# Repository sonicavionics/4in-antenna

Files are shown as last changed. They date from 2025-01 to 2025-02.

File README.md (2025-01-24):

# Antenna Module Repository

Use Export KiCad Images Workflow

---

<div align="center">
  <div>
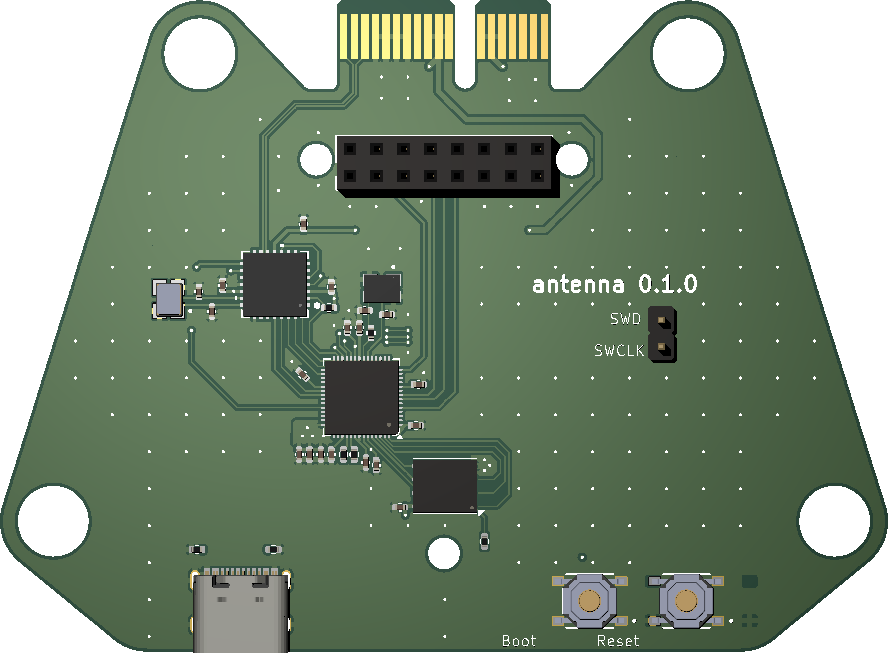
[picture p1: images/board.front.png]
    
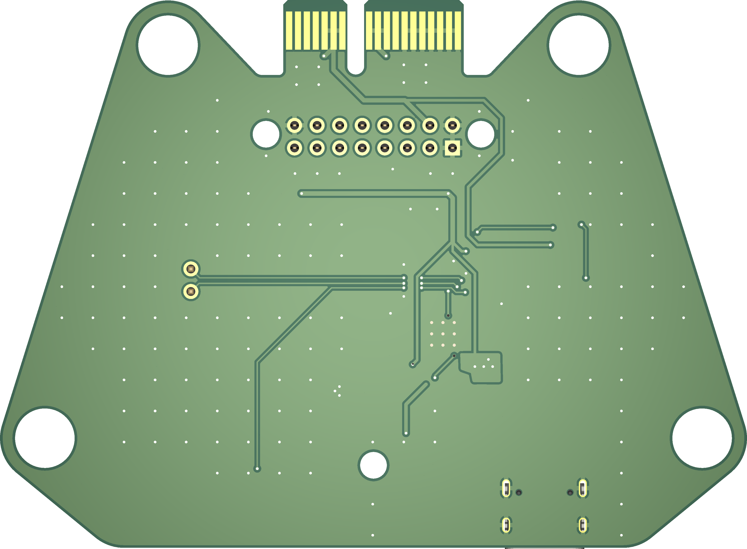
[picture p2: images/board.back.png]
    
    <p><em>3D Render</em></p>
  </div>
  <br>

  <div>
    Schematic<br>
    <p><em>Schematic</em></p>
  </div>
  <br>
  
  <div>
    Front
    Back<br>
    <em>Footprint</em>
  </div>
</div>

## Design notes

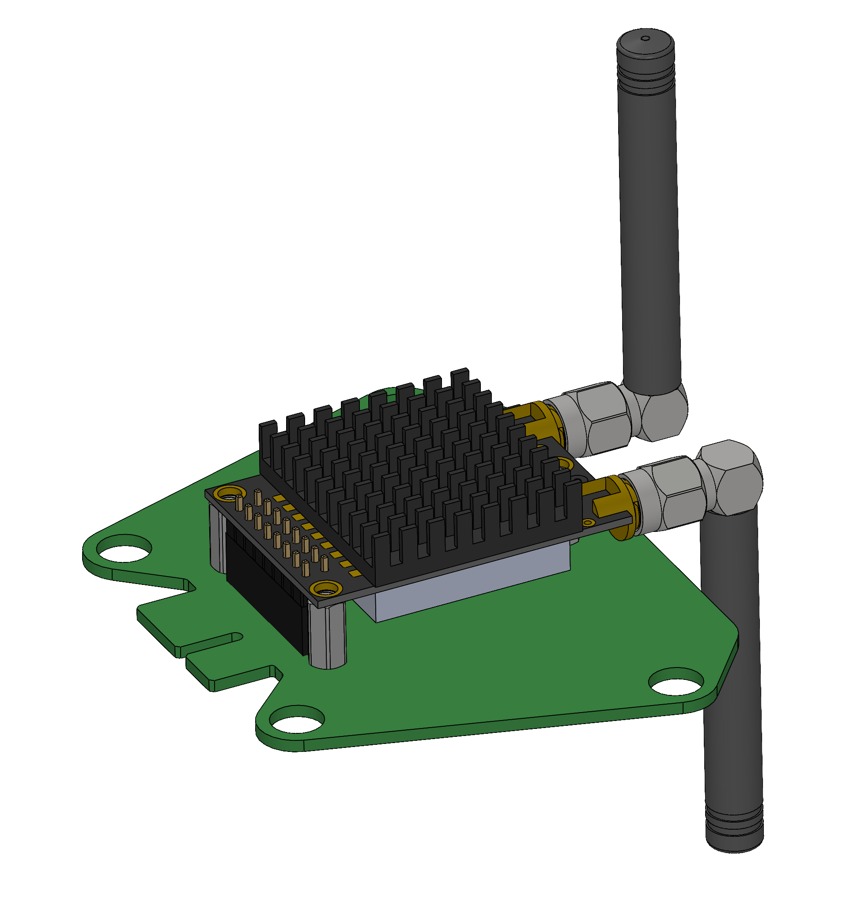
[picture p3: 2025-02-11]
mcad_exports/images/rfd_board.PNG

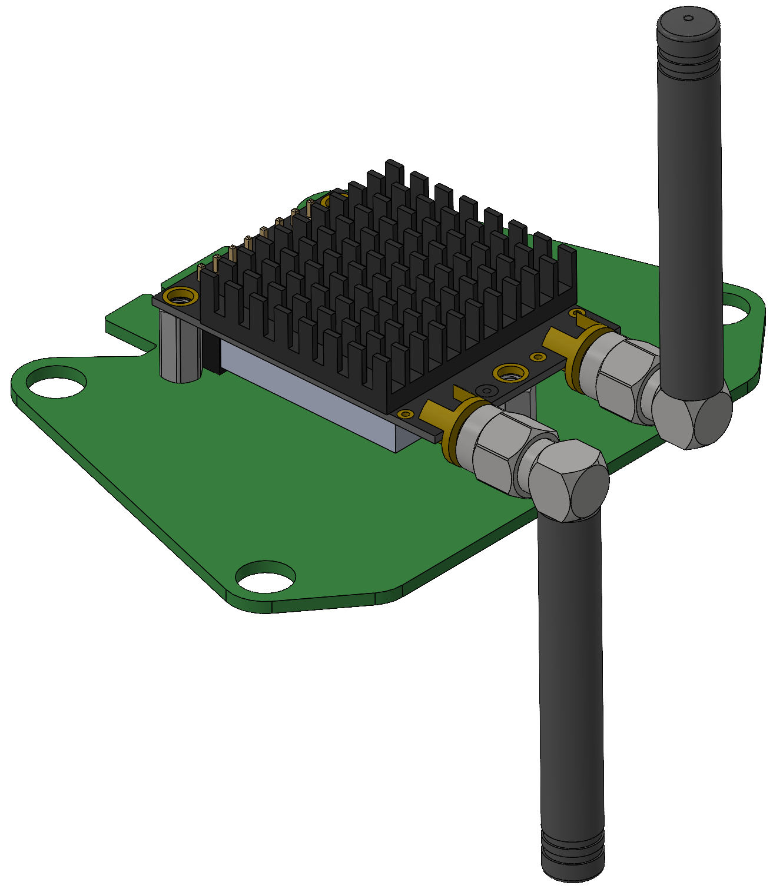
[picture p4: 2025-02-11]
mcad_exports/images/rfd_board2.PNG

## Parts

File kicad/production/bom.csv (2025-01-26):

Designator | Footprint | Quantity | Value | LCSC Part #
C10, C11 | 0402 | 2 | 15p | C1548
C206, C207, C209, C211, C212, C213, C214, C215, C216, C40, C90, C92, C93 | 0402 | 13 | 100n | C307331
C208, C210 | 0402 | 2 | 1u | C52923
C94, C95 | 0402 | 2 | 22p | C1555
J5 | PinSocket_2x08_P2.54mm_Vertical | 1 | Conn_02x08_Odd_Even
J6 | USB_C_Receptacle_Palconn_UTC16-G | 1 | USB_C_Receptacle_USB2.0_16P | C2765186
R12, R30 | 0402 | 2 | 1k | C11702
R203, R204 | 0402 | 2 | 27 | C25100
R3, R4 | 0402 | 2 | 5.1k | C25905
R91 | 0402 | 1 | 10k | C25744
S1, S2 | SW_TS-1187A-B-A-B | 2 | TS-1187A-B-A-B | C318884
U2 | QFN-56-1EP_7x7mm_P0.4mm_EP3.2x3.2mm | 1 | RP2040 | C2040
U4 | WSON-8-1EP_6x5mm_P1.27mm_EP3.4x4.3mm | 1 | W25Q128JVP | C190862
U9 | QFN28_6X6MC_MCH | 1 | MCP25625T-E/ML | C191253
X1 | ABM8-272-T3_ABR | 1 | ABM8-272-T3 | C20625731
Y2 | OSC_X322516MLB4SI | 1 | X322516MLB4SI | C12668

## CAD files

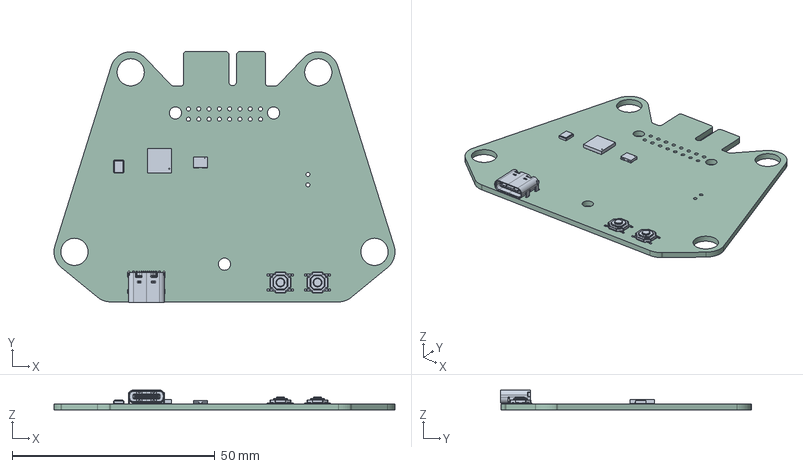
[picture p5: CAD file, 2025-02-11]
images/board.step
84.1 x 61.9 x 4.91 mm
X322516MLB4SI
TS-1187A-B-A-B x 2
QFN28_6X6MC_MCH
USB_C_Receptacle_GCT_USB4105-xx-A_16P_TopMnt_Horizontal
ABM8-272-T3_ABR
antenna_PCB

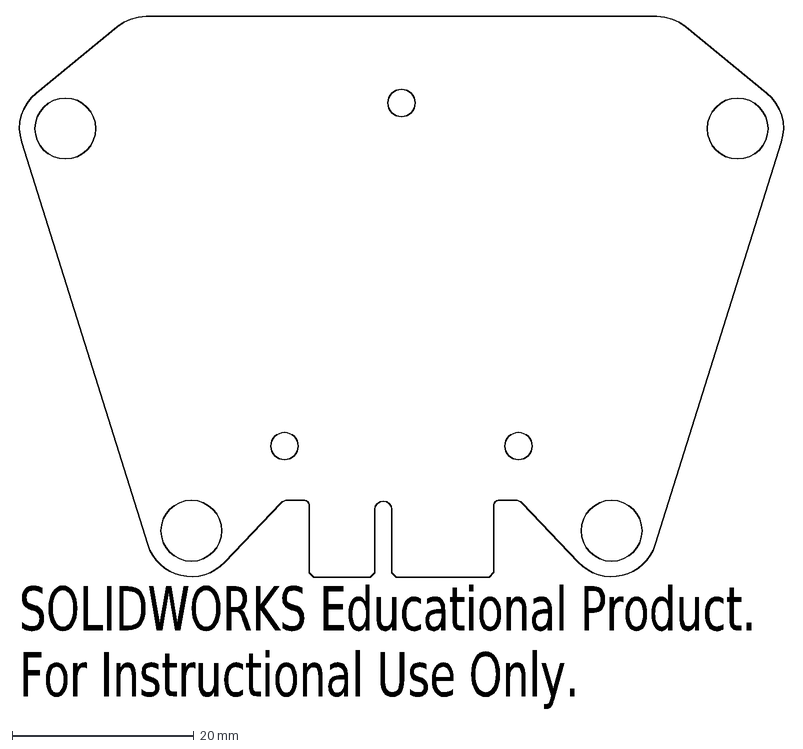
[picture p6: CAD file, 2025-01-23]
mcad_exports/dxf/rfd_card.DXF
SOLIDWORKS Educational Product.
For Instructional Use Only.

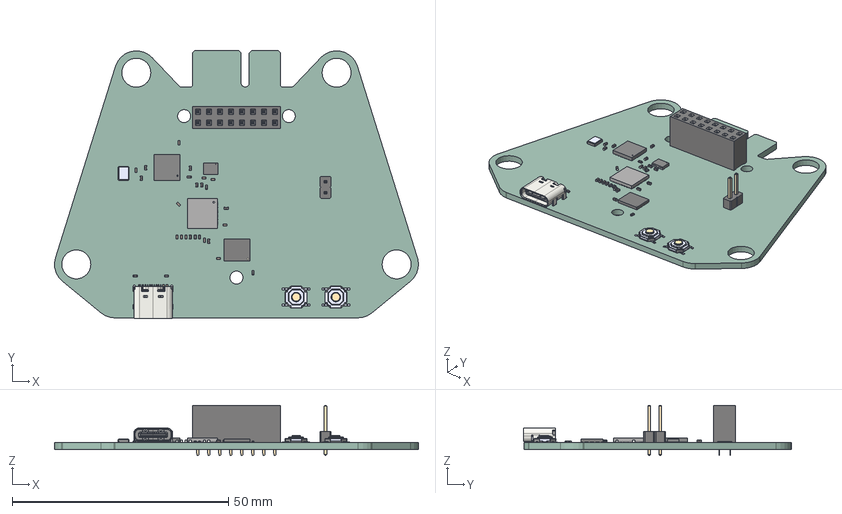
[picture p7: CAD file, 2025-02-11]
solidworks/kicad_pcb.step
84.1 x 61.9 x 11.6 mm
WSON-8-1EP_6x5mm_P1.27mm_EP3.4x4.3mm
C_0402_1005Metric x 19
R_0402_1005Metric x 7
X322516MLB4SI
TS-1187A-B-A-B x 2
USB_C_Receptacle_16P_TopMnt_Horizontal_GCT_USB4105-xx-A
PinSocket_2x08_P2.54mm_Vertical
QFN_56_1EP_7x7mm_P04mm_EP32x32mm
PinHeader_1x02_P254mm_Vertical
antenna_PCB

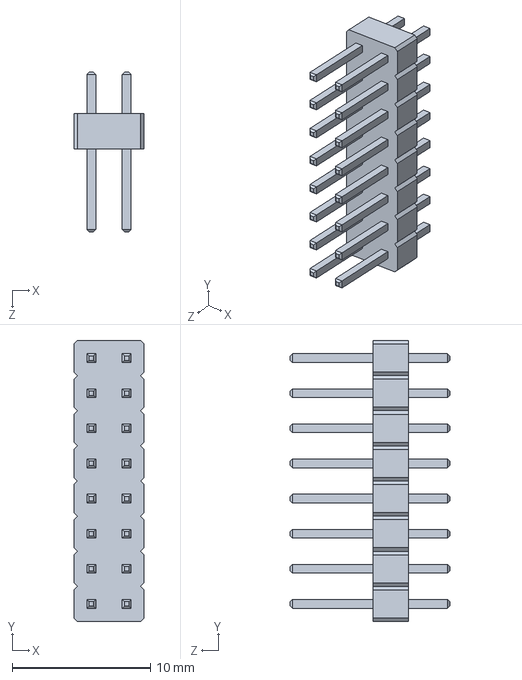
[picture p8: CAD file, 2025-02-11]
solidworks/PinHeader_2x08_P2.54mm_Vertical.SLDPRT
5.08 x 20.3 x 11.5 mm

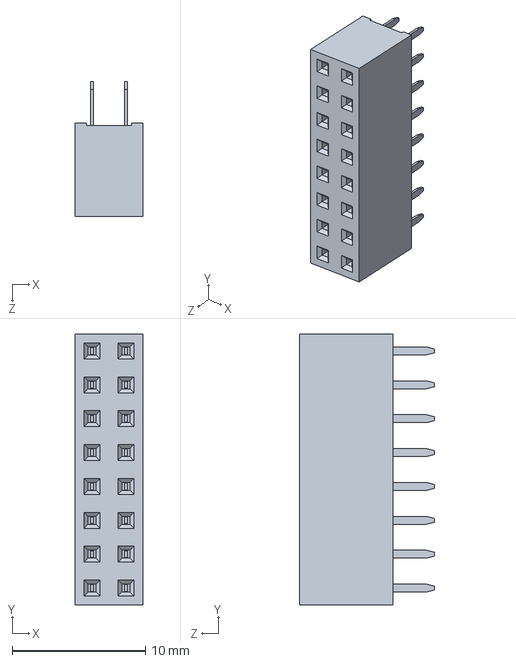
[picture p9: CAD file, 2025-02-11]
solidworks/PinSocket_2x08_P2.54mm_Vertical.SLDPRT
5.08 x 20.3 x 10.1 mm

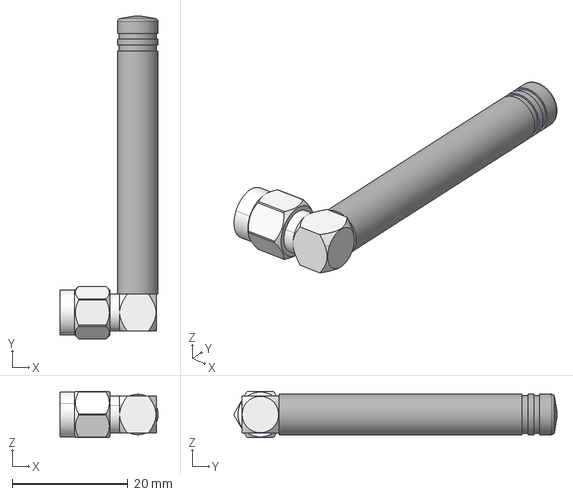
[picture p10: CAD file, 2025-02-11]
solidworks/GSM_ANTENNA_45mm_90deg.step
16.9 x 55.7 x 8.00 mm
RP-SMA FEMALE TO 90DEG MALE

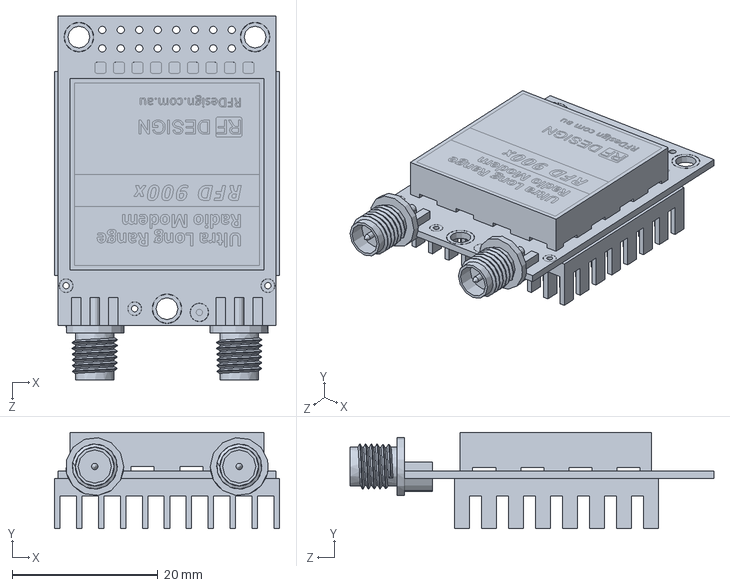
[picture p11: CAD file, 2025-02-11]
solidworks/RFD 900+.SLDPRT
30.9 x 13.2 x 50.0 mm

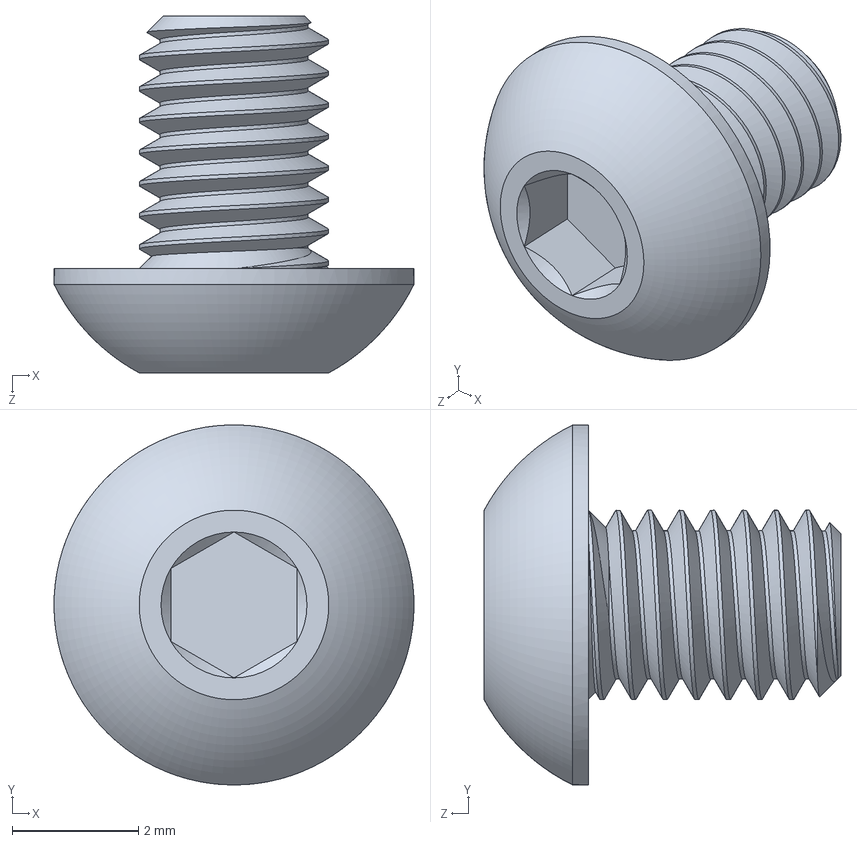
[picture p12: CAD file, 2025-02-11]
solidworks/92095A471_Button Head Hex Drive Screw.SLDPRT
5.70 x 5.70 x 5.65 mm

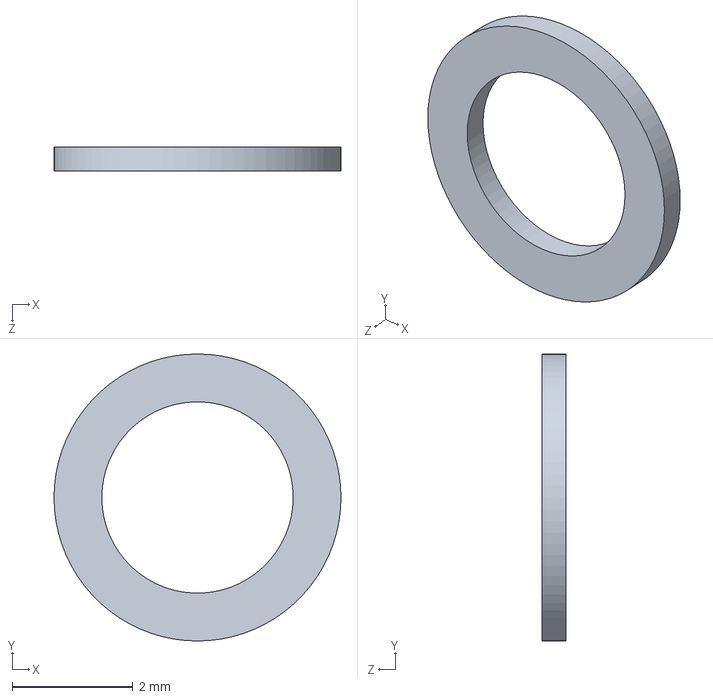
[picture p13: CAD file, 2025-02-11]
solidworks/97022A879_316 Stainless Steel Ring Shim.SLDPRT
4.76 x 4.76 x 0.406 mm

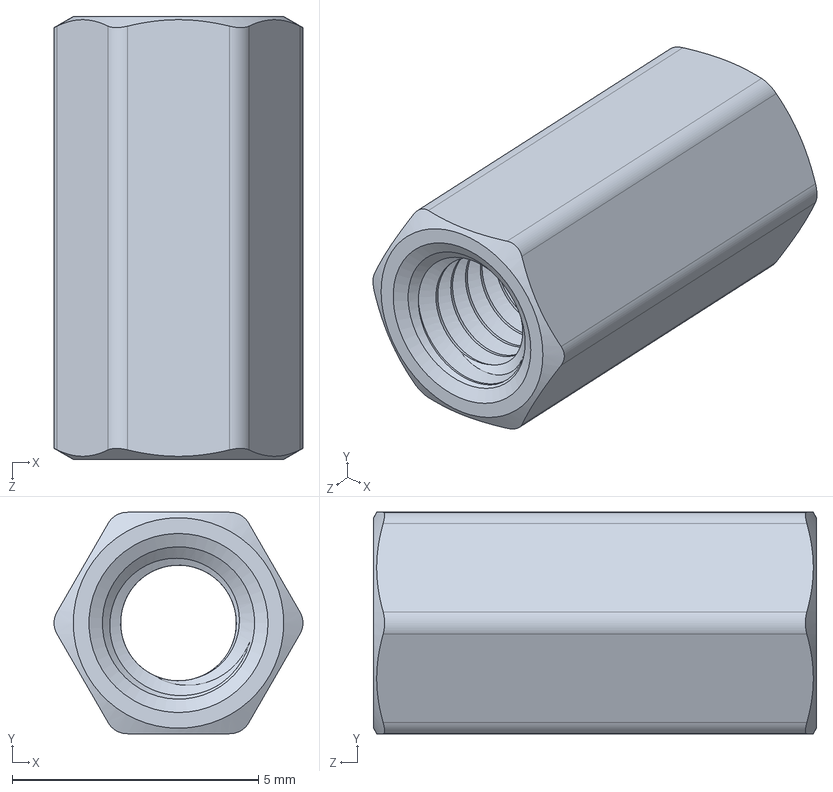
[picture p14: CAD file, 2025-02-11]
solidworks/94868A719_Female Threaded Hex Standoff(1).SLDPRT
5.06 x 4.50 x 9.00 mm

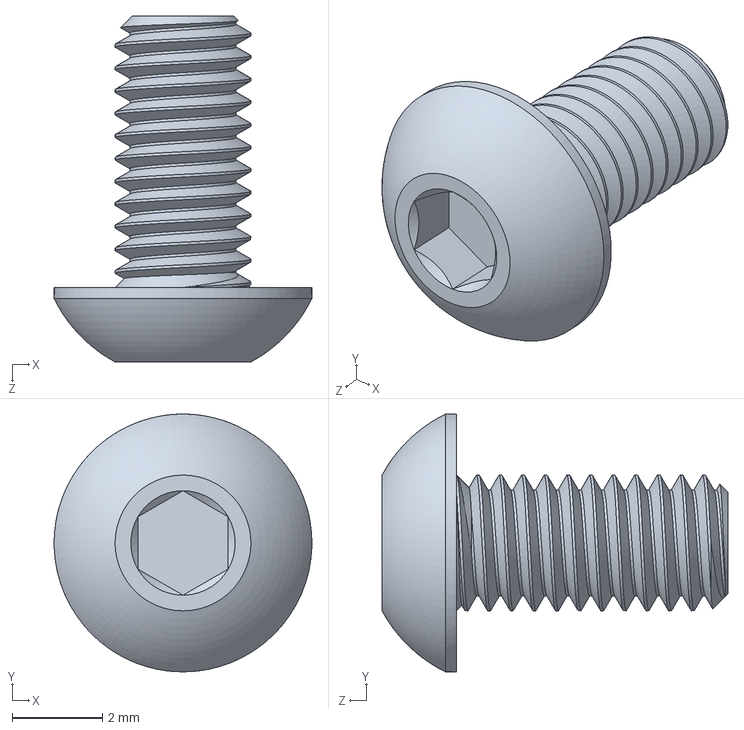
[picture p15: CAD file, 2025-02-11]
solidworks/92095A179_Button Head Hex Drive Screw.SLDPRT
5.70 x 5.70 x 7.65 mm

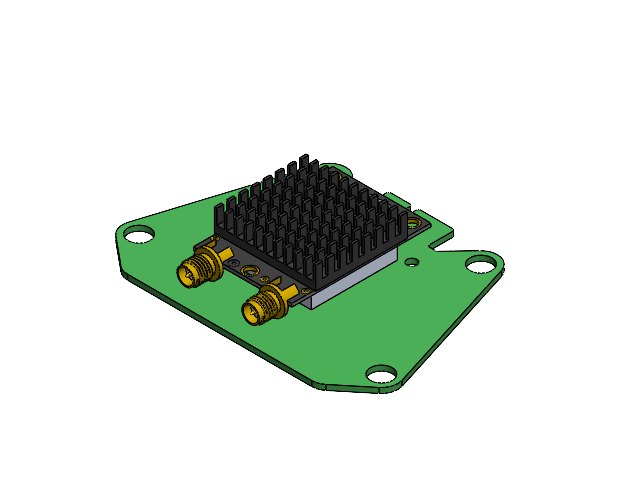
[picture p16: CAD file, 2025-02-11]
solidworks/rfd_board1.SLDASM
RFD 900+
board

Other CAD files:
solidworks/RP-SMA FEMALE TO 90DEG MALE_1.step.SLDPRT

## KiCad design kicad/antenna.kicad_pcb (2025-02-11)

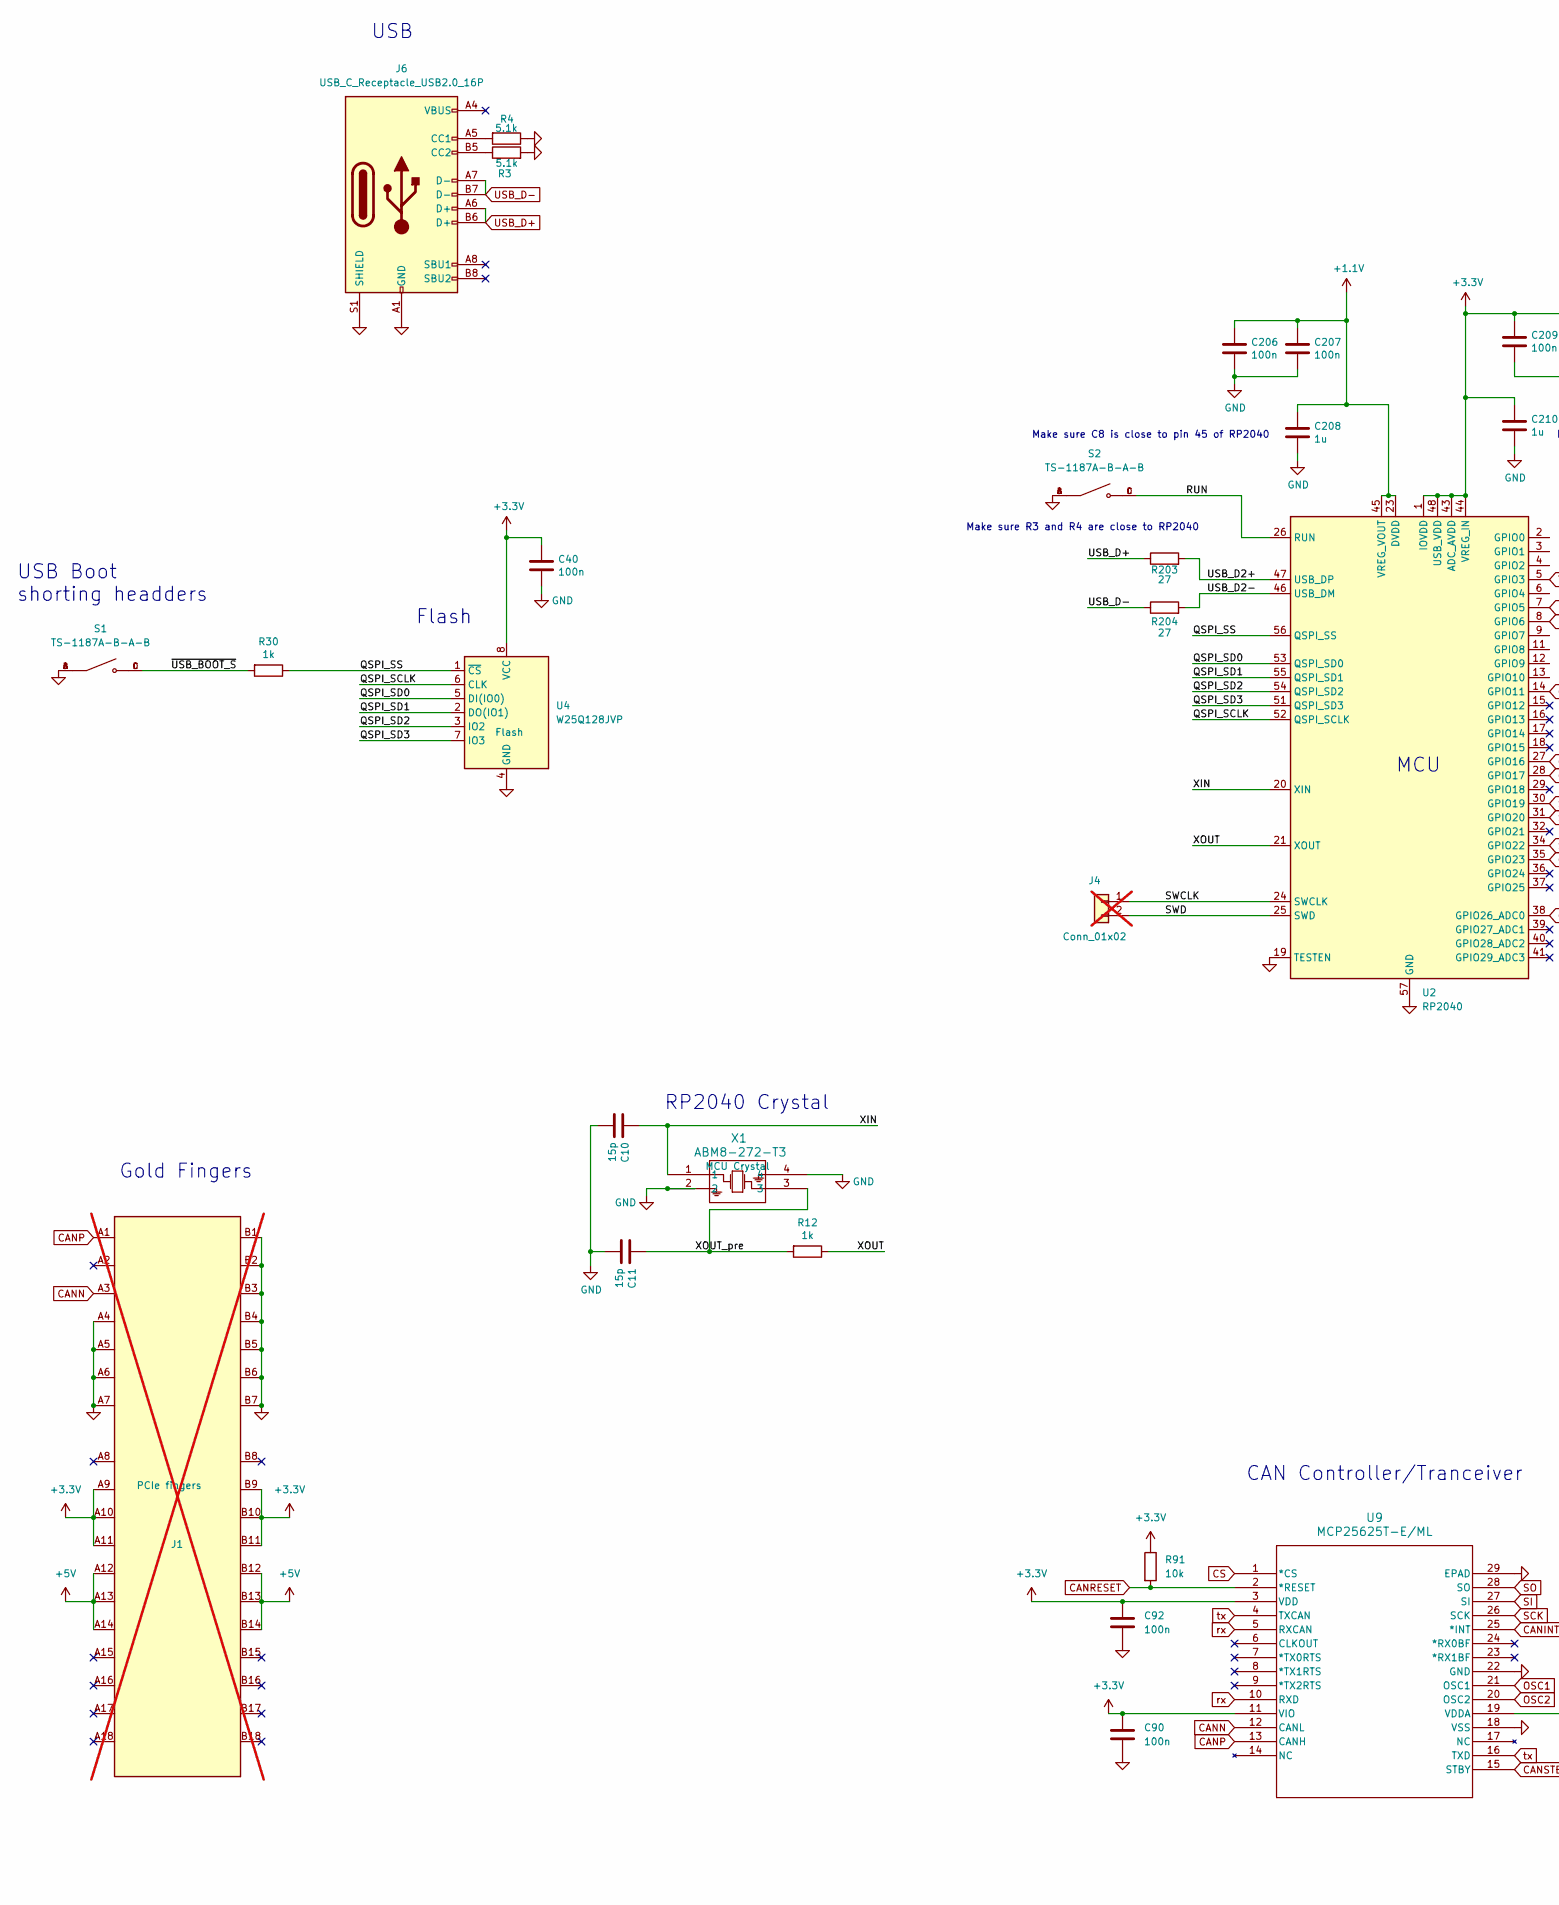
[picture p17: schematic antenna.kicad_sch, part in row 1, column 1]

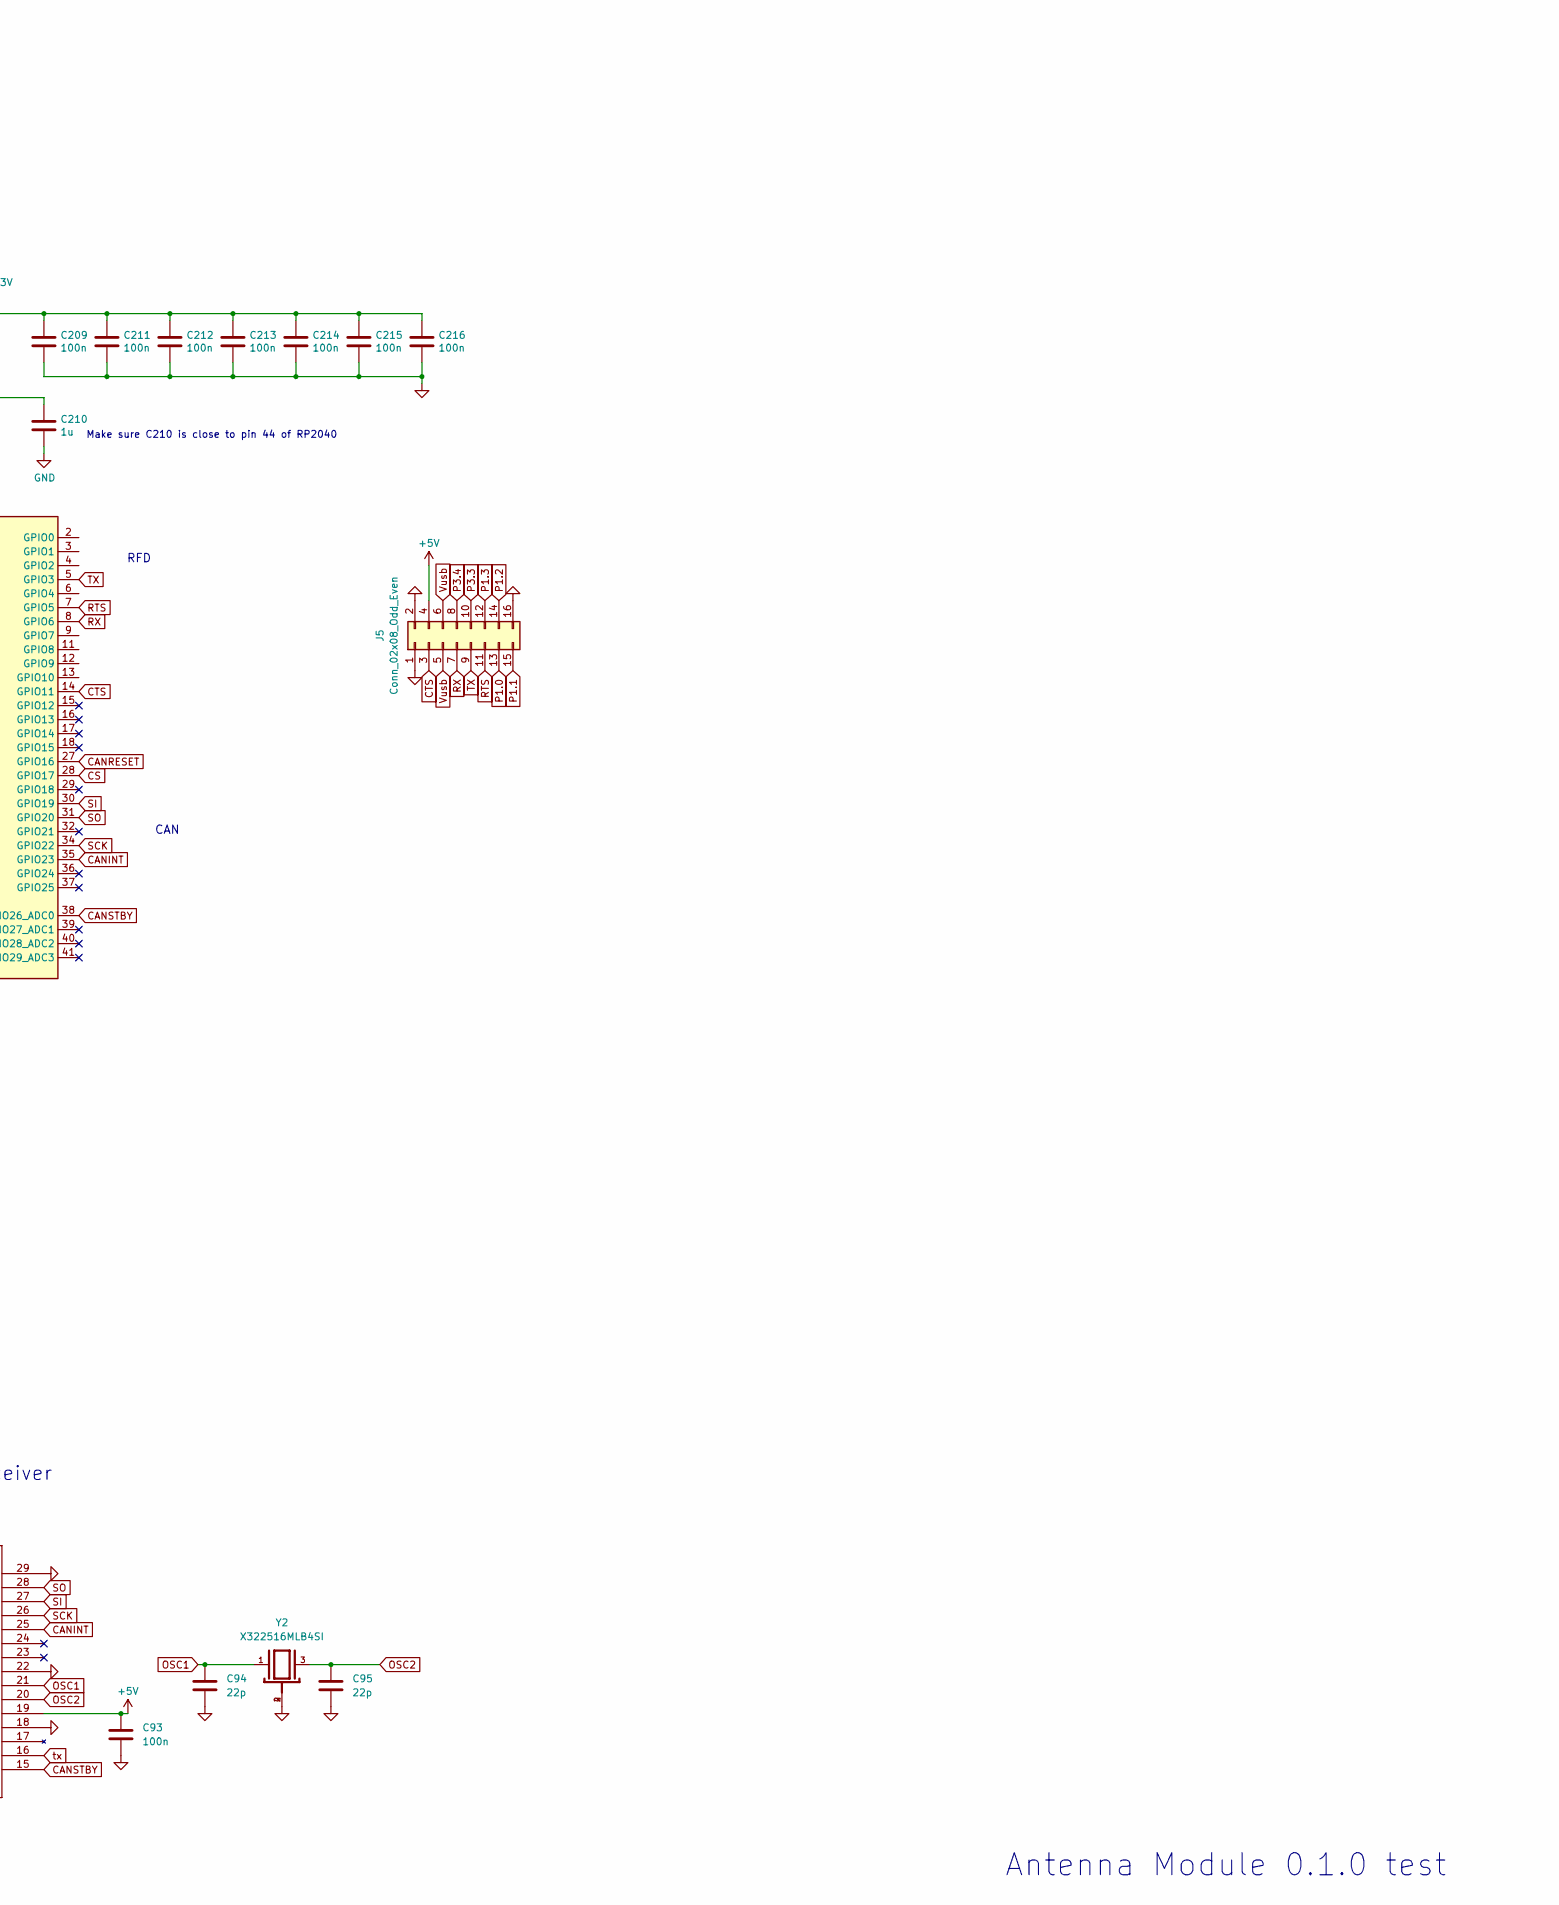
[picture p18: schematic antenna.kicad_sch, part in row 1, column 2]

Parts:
C10, C11: 15p; C_0402_1005Metric; LCSC Part # C1548
C40, C90, C92, C93, C206, C207, C209, C211, C212, C213, C214, C215, C216: 100n; C_0402_1005Metric; LCSC Part # C307331
C94, C95: 22p; C_0402_1005Metric; LCSC Part # C1555
C208, C210: 1u; C_0402_1005Metric; LCSC Part # C52923
J1: Bus_PCI_Express_x1; BUS_PCIexpress_x1; LCSC Part # n/a; not fitted
J4: Conn_01x02; PinHeader_1x02_P2.54mm_Vertical; LCSC Part # n/a; not fitted
J5: Conn_02x08_Odd_Even; PinSocket_2x08_P2.54mm_Vertical
J6: USB_C_Receptacle_USB2.0_16P; USB_C_Receptacle_Palconn_UTC16-G; LCSC Part # C2765186
R3, R4: 5.1k; R_0402_1005Metric; LCSC Part # C25905
R12, R30: 1k; R_0402_1005Metric; LCSC Part # C11702
R91: 10k; R_0402_1005Metric; LCSC Part # C25744
R203, R204: 27; R_0402_1005Metric; LCSC Part # C25100
S1, S2: TS-1187A-B-A-B; SW_TS-1187A-B-A-B; PARTREV A0; LCSC Part # C318884
U2: RP2040; QFN-56-1EP_7x7mm_P0.4mm_EP3.2x3.2mm; LCSC C2040
U4: W25Q128JVP; WSON-8-1EP_6x5mm_P1.27mm_EP3.4x4.3mm; LCSC C190862
U9: MCP25625T-E/ML; QFN28_6X6MC_MCH; LCSC Part # C191253
X1: ABM8-272-T3; ABM8-272-T3_ABR; LCSC Part # C20625731
Y2: X322516MLB4SI; OSC_X322516MLB4SI; PARTREV N/A; LCSC Part # C12668

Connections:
+1.1V: C206.1, C207.1, C208.1, U2.23 (DVDD), U2.45 (VREG_VOUT), U2.50 (DVDD)
+3.3V: C40.1, C90.1, C92.1, C209.1, C210.1, C211.1, C212.1, C213.1, C214.1, C215.1, C216.1, J1.A9 (+3.3V), J1.A10 (+3.3V), J1.A11 (~PERST), J1.B9 (JTAG1), J1.B10 (3.3Vaux), J1.B11 (~WAKE), R91.1, U2.1 (IOVDD), U2.10 (IOVDD), U2.22 (IOVDD), U2.33 (IOVDD), U2.42 (IOVDD), U2.43 (ADC_AVDD), U2.44 (VREG_IN), U2.48 (USB_VDD), U2.49 (IOVDD), U4.8 (VCC), U9.3 (VDD), U9.11 (VIO)
+5V: C93.1, J1.A12 (GND), J1.A13 (REFCLK+), J1.A14 (REFCLK-), J1.B12 (RSVD), J1.B13 (GND), J1.B14 (PETp0), J5.4, U9.19 (VDDA)
/QSPI_SCLK: U2.52 (QSPI_SCLK), U4.6 (CLK)
/QSPI_SD0: U2.53 (QSPI_SD0), U4.5 (DI(IO0))
/QSPI_SD1: U2.55 (QSPI_SD1), U4.2 (DO(IO1))
/QSPI_SD2: U2.54 (QSPI_SD2), U4.3 (IO2)
/QSPI_SD3: U2.51 (QSPI_SD3), U4.7 (IO3)
/QSPI_SS: R30.1, U2.56 (QSPI_SS), U4.1 (~CS)
/RUN: S2.C, S2.D, U2.26 (RUN)
/SWCLK: J4.1, U2.24 (SWCLK)
/SWD: J4.2, U2.25 (SWD)
/USB_D2+: R203.2, U2.47 (USB_DP)
/USB_D2-: R204.2, U2.46 (USB_DM)
/XIN: C10.1, U2.20 (XIN), X1.1
/XOUT: R12.1, U2.21 (XOUT)
/XOUT_pre: C11.1, R12.2, X1.3
/~USB_BOOT_S: R30.2, S1.C, S1.D
CANINT: U2.35 (GPIO23), U9.25 (*INT)
CANN: J1.A3 (+12V), U9.12 (CANL)
CANP: J1.A1 (~PRSNT1), U9.13 (CANH)
CANRESET: R91.2, U2.27 (GPIO16), U9.2 (*RESET)
CANSTBY: U2.38 (GPIO26_ADC0), U9.15 (STBY)
CS: U2.28 (GPIO17), U9.1 (*CS)
CTS: J5.3, U2.14 (GPIO11)
GND: C10.2, C11.2, C40.2, C90.2, C92.2, C93.2, C94.2, C95.2, C206.2, C207.2, C208.2, C209.2, C210.2, C211.2, C212.2, C213.2, C214.2, C215.2, C216.2, J1.A4 (GND), J1.A5 (JTAG2), J1.A6 (JTAG3), J1.A7 (JTAG4), J1.B1 (+12V), J1.B2 (+12V), J1.B3 (+12V), J1.B4 (GND), J1.B5 (SMCLK), J1.B6 (SMDAT), J1.B7 (GND), J5.1, J5.2, J5.16, J6.A1 (GND), J6.A12 (GND), J6.B1 (GND), J6.B12 (GND), J6.S1 (SHIELD), R3.2, R4.1, S1.A, S1.B, S2.A, S2.B, U2.19 (TESTEN), U2.57 (GND), U4.4 (GND), U9.18 (VSS), U9.22 (GND), U9.29 (EPAD), X1.2, X1.4, Y2.2, Y2.4
unnamed: J6.A5 (CC1), R4.2
unnamed: J6.B5 (CC2), R3.1
OSC1: C94.1, U9.21 (OSC1), Y2.1
OSC2: C95.1, U9.20 (OSC2), Y2.3
P1.0: J5.13
P1.1: J5.15
P1.2: J5.14
P1.3: J5.12
P3.3: J5.10
P3.4: J5.8
RTS: J5.11, U2.7 (GPIO5)
RX: J5.7, U2.8 (GPIO6)
SCK: U2.34 (GPIO22), U9.26 (SCK)
SI: U2.30 (GPIO19), U9.27 (SI)
SO: U2.31 (GPIO20), U9.28 (SO)
TX: J5.9, U2.5 (GPIO3)
USB_D+: J6.A6 (D+), J6.B6 (D+), R203.1
USB_D-: J6.A7 (D-), J6.B7 (D-), R204.1
Vusb: J5.5, J5.6
rx: U9.5 (RXCAN), U9.10 (RXD)
tx: U9.4 (TXCAN), U9.16 (TXD)

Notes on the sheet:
Make sure C210 is close to pin 44 of RP2040
Make sure C8 is close to pin 45 of RP2040
RP2040 Crystal
USB
Make sure R3 and R4 are close to RP2040
CAN
RFD
USB Boot shorting headders
Antenna Module 0.1.0 test
Gold Fingers
MCU
CAN Controller/Tranceiver
Flash

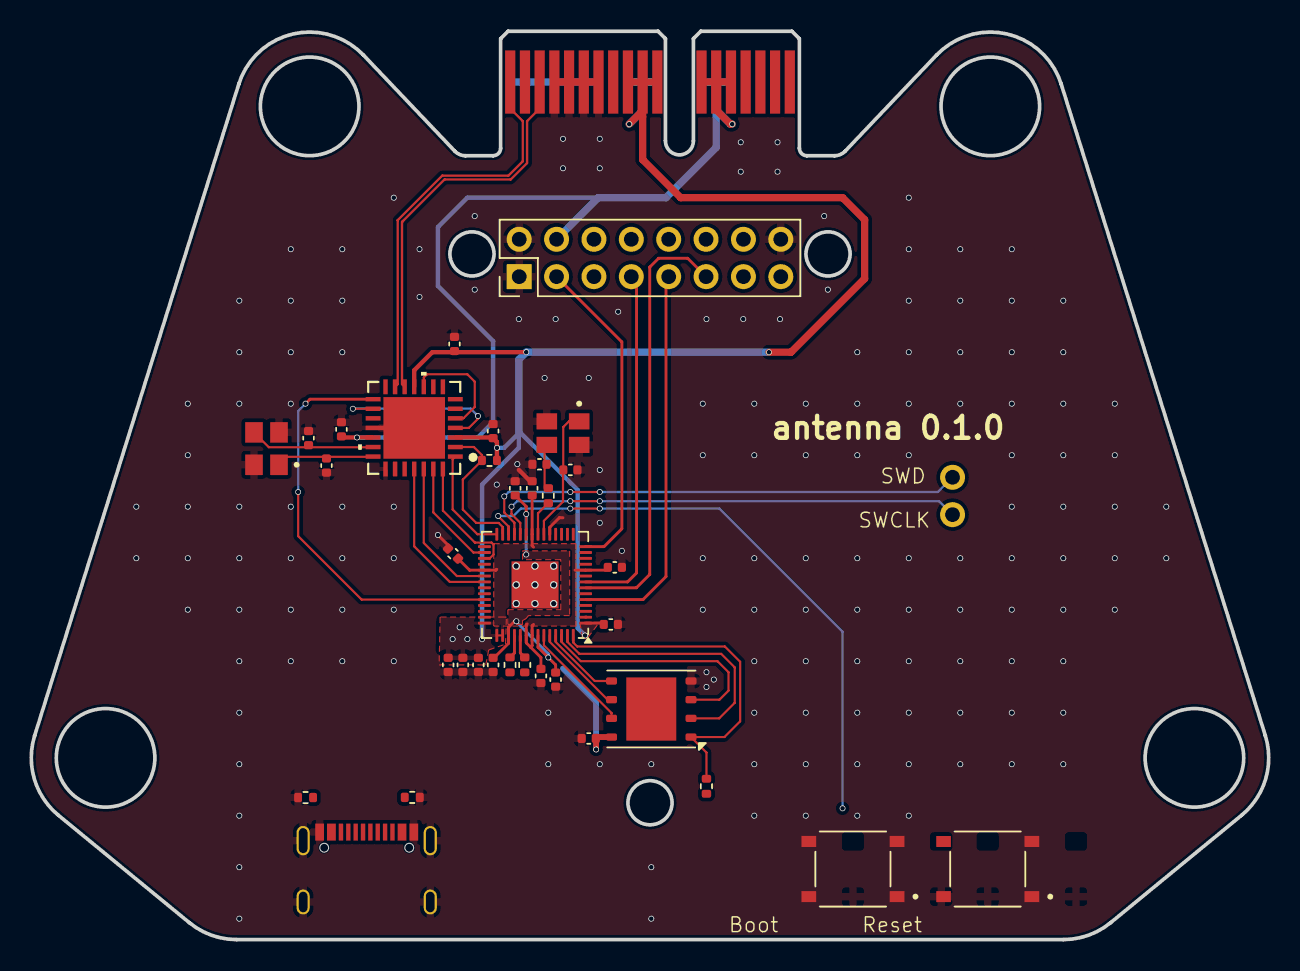
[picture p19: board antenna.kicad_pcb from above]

Board: 2 copper layers, 84.1 x 61.7 mm, 37 parts (1 on the bottom side), 41 nets.

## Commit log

2025-01-23 Auto-exported schematic, PCB, and 3D model
    [board.step]
2025-01-24 update DXF to new hole positions
    [antenna.kicad_pcb, antenna.kicad_sch]
2025-01-25 update positioning of all chips to fit rfd900x
    [antenna.kicad_pcb, antenna.kicad_sch]
2025-01-26 update kicad antenna board
    [bom.csv, designators.csv, kicad_pcb.step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]
2025-01-26 Update images
    [board.step]
2025-02-11 add MCAD files
    [92095A179_Button Head Hex Drive Screw.SLDPRT, 92095A471_Button Head Hex Drive Screw.SLDPRT, 94868A719_Female Threaded Hex Standoff(1).SLDPRT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]
2025-02-11 reposition usb ports and buttons
    [antenna.kicad_pcb, kicad_pcb.step, rfd_card.DXF]
